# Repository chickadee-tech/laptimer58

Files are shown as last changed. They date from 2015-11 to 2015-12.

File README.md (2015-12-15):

# chickadee-laptimer-pcb
PCB design files for Chickadee Lap Timer.

See subfolders for licenses. Code is typically MIT Licensed and PCB designs are typically Creative Commons BY-SA.

Kicad files use components available in https://github.com/chickadee-tech/kicad-libs. It is assumed that this directory is ../shared/kicad/libraries/public/ relative to the root of this repository. You may find absolute paths that still need to be fixed. Please provide a pull request to fix those.

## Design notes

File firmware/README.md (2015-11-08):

# chickadee-firmware
Firmware for chickadee devices.

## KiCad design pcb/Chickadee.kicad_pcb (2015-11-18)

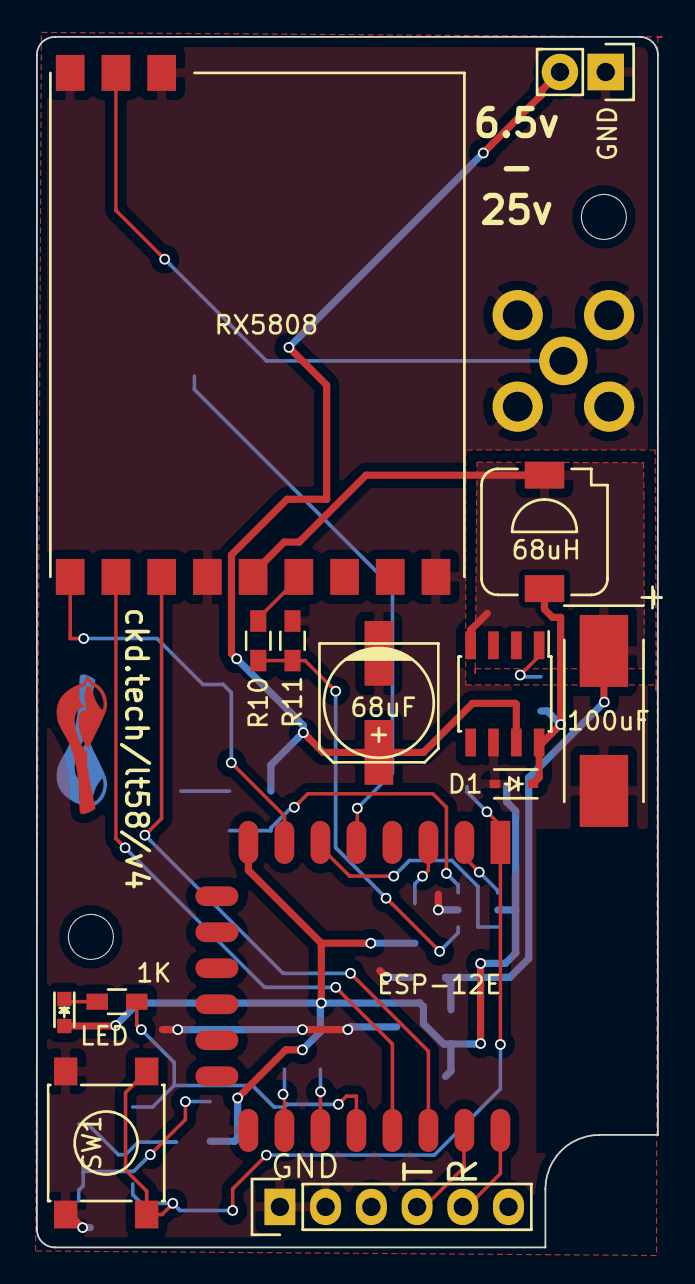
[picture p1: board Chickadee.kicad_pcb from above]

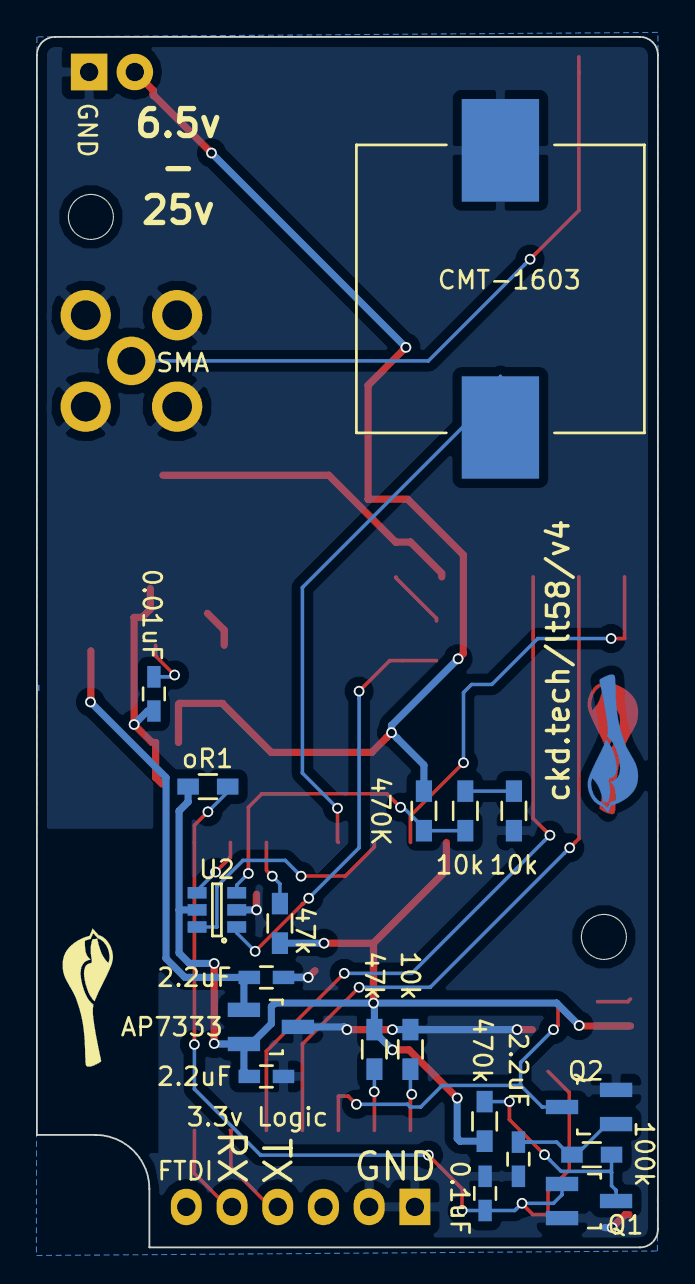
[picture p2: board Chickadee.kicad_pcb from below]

Board: 2 copper layers, 34.5 x 67.2 mm, 34 parts (19 on the bottom side), 27 nets.

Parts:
C1: 0.1uF; C_0603_HandSoldering
C2, C3, C4: 2.2uF; C_0603_HandSoldering
CB1: 0.01uF; C_0603_HandSoldering
Cin1: 68uF; c_elec_6.3x7.7
Cout1: 100uF; TantalC_SizeD_EIA-7343_HandSoldering
D1: SD103BWS-TP; SOD-323
D2: LED; LED-0603
J1: SMA; SMA-Jack-Straight
L1: 68uH; SLF7032
LS1: CMT-1603; CMT-1603-SMT
P1: FTDI; Pin_Header_Straight_1x06
P2: CONN_01X02; Pin_Header_Straight_1x02
Q1, Q2: Q_NMOS_GSD; SOT-23_Handsoldering
R1: 470k; R_0603_HandSoldering
R2: 100k; R_0603_HandSoldering
R3, R5: 47k; R_0603_HandSoldering
R4: 1K; R_0603_HandSoldering
R6, R8, R9, R11: 10k; R_0603_HandSoldering
R7: 470K; R_0603_HandSoldering
R10: 1k; R_0603_HandSoldering
RF1: RX5808; rx5808
SW1: SW_PUSH; SW_SPST_PTS645
U1: ESP-12E
U2: 74LVC1G3157; SOT-23-6
U3: LM2674M-3.3; SOIC-8_3.9x4.9mm_Pitch1.27mm
U4: AP7333; SOT-23_Handsoldering
oR1: 10k; R_0603_HandSoldering

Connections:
+3V3: C4.1, D2.2, R1.1, R3.2, R5.1, U1.8, U2.5, U4.2, oR1.1
+5V: C3.1, Cout1.1, L1.1, RF1.8, U3.4, U4.1
+BATT: Cin1.1, P2.2, R7.1, U3.7
/5V/3V3 Regulator/5uf: CB1.2, D1.1, L1.2, U3.8
/ADC_SELECT: U1.6, U2.6
/CLK: RF1.6, U1.20
/DATA: RF1.4, U1.7
/ESP-Reset/GPIO0: Q2.3, R4.2, U1.18
/ESP-Reset/RESET: C1.1, Q1.1, SW1.2, U1.1, oR1.2
/LE: RF1.5, U1.19
/RFIN: J1.1, RF1.2
/RSSI: R10.1, RF1.9
/RXI: P1.5, U1.22
/SHARED_ADC: U1.2, U2.4
/TXO: P1.4, U1.21
GNDPWR: C1.2, C2.2, C3.2, C4.2, Cin1.2, Cout1.2, D1.2, J1.2, J1.3, J1.4, J1.5, LS1.2, P1.1, P1.2, P2.1, Q1.2, Q2.2, R6.1, R9.2, R11.2, RF1.1, RF1.3, RF1.7, RF1.12, SW1.1, U1.15, U2.2, U3.6, U4.3
unnamed: C2.1, Q2.1, R2.1
unnamed: CB1.1, U3.1
unnamed: D2.1, R4.1
unnamed: LS1.1, U1.5
unnamed: Q1.3, R1.2, R2.2
unnamed: R3.1, U1.3
unnamed: R5.2, U1.17
unnamed: R6.2, U1.16
unnamed: R7.2, R8.1, U2.3
unnamed: R8.2, R9.1
unnamed: R10.2, R11.1, U2.1

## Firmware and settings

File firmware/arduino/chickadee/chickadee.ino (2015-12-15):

#include <ESP8266WiFi.h>
#include <WiFiUDP.h>
#include <EEPROM.h>

// Wifi related globals.
const char* SSID = "chickadee";
const char* PASSWORD = "iflyfast";

const IPAddress MULTICAST_ADDRESS(239, 249, 134, 147);
const uint16_t PORT = 59734;

// Radio related globals.
const unsigned int TUNE_TIME_MS = 30; // 30

// Cross-power up globals.
const uint32_t EEPROM_VERSION = 1;

const uint16_t MAX_JOIN_DELAY = 15000;

#define RSSI_READS 3 // used to be 10 but took 4ms

const int BOARD_LED = 0;
const int ESP_LED = 2;
const int SPEAKER = 14;
const int ADC_SELECT = 12;

const int RCV_CHIP_SELECT = 4;
const int RCV_CLK = 5;
const int RCV_DATA = 13;

const uint8_t PACKET_TYPE_NEW_CLIENT = 1;
const uint8_t PACKET_TYPE_NEW_PEER = 2;
const uint8_t PACKET_TYPE_I_AM_AP = 3;

const uint8_t PEER_LED_ON_CYCLE_COUNT = 2;
const uint8_t PEER_LED_BREAK_CYCLE_COUNT = 20;

const uint8_t ERROR_NO_WIFI = 1;
const uint8_t ERROR_MAX_CLIENTS = 2;
const uint8_t ERROR_MAX_PEERS = 3;

int errorCode = -1;

unsigned long lastReadTime;
unsigned long lastTuneTime;

IPAddress ourIp;

WiFiUDP udp;

// If we are the AP we must also forward packets from peers to clients.
bool isAP = false;

#define TCP_SERVER_PORT 59736
WiFiServer server(TCP_SERVER_PORT);

uint8_t controlPacket[] = {0, 0, 0, 0};

void setup() {
  Serial.begin(115200);
  delay(10);

  uint32_t chipId = ESP.getChipId();
  Serial.println(chipId);

  // Get our file counter.
  EEPROM.begin(12);
  uint32_t storedChipId;
  EEPROM.get(0, storedChipId);
  //Serial.println(storedChipId);
  // Initialize the eeprom completely.
  if (storedChipId != chipId) {
    EEPROM.put(0, chipId);
    EEPROM.put(4, EEPROM_VERSION);
  }
  EEPROM.end();

  pinMode(0, OUTPUT);
  
  // ADC_SELECT switches between measuring RSSI and battery voltage. v3 boards
  // don't have the battery voltage divider hooked up so we just set it to the
  // RSSI for good. LOW is the battery voltage.
  pinMode(ADC_SELECT, OUTPUT);
  digitalWrite(ADC_SELECT, HIGH);

  pinMode(BOARD_LED, OUTPUT);

  pinMode(ESP_LED, OUTPUT);
  digitalWrite(ESP_LED, HIGH);

  pinMode(RCV_DATA, OUTPUT);
  pinMode(RCV_CLK, OUTPUT);
  pinMode(RCV_CHIP_SELECT, OUTPUT);

  // Scan for an existing network.
  WiFi.mode(WIFI_STA);
  WiFi.disconnect();
  delay(100);

  int network_count = WiFi.scanNetworks();

  bool found_network = false;
  for (int i = 0; i < network_count; i++) {
    found_network = String(WiFi.SSID(i)).equals(String(SSID));
    if (found_network) {
      break;
    }
  }

  if (!found_network) {
    WiFi.mode(WIFI_AP_STA);
    WiFi.softAP(SSID, PASSWORD);
    ourIp = WiFi.softAPIP();

    Serial.println("Created network");
    isAP = true;
  } else {
    WiFi.begin(SSID, PASSWORD);
    uint16 total_delay = 0;
    while (WiFi.status() != WL_CONNECTED && total_delay < MAX_JOIN_DELAY) {
      delay(100);
      total_delay += 100;
    }
    if (WiFi.status() != WL_CONNECTED) {
      //Serial.println("WiFi join failed.");
      WiFi.printDiag(Serial);
      errorCode = ERROR_NO_WIFI;
      return;
    }
    
    Serial.println("Joined existing network.");
    ourIp = WiFi.localIP();
  }
  server.begin();
  //Serial.println(ourIp);
  udp.beginMulticast(ourIp, MULTICAST_ADDRESS, PORT);
  udp.beginPacketMulticast(MULTICAST_ADDRESS, PORT, ourIp);
  controlPacket[0] = PACKET_TYPE_NEW_PEER;
  controlPacket[1] = 0;
  controlPacket[2] = TCP_SERVER_PORT & 0xff;
  controlPacket[3] = TCP_SERVER_PORT >> 8;
  udp.write(controlPacket, sizeof(controlPacket));
  udp.endPacket();
}

// One iteration byte to detect missed packets.
// Four bytes for the time.
// Two bytes for the frequency.
// Two bytes for the strength.
uint8_t packet_size = 9;

uint8_t packetNo = 0;
uint16_t frequencies[] = {5800, 5740, 0, 0, 0, 0, 0};
uint16_t f_register[] = {0x2984, 0x2906, 0, 0, 0, 0, 0};
uint16_t lastValue = 0;
bool increasing = true;
uint16_t tuningFrequency = 0;
uint16_t tunedFrequency = 0;

// Clients are devices that want to get the data streamed back to them.
const int MAX_CLIENTS = 4;
WiFiClient clients[MAX_CLIENTS];
uint8_t numClients = 0;

// Only the AP node has peers. They are other devices that wish to send their data to the clients of the AP.
const int MAX_PEERS = 4;
WiFiClient peer[MAX_PEERS];
uint8_t numPeers = 0;

#define WIFI_MTU 1400 // buffer writes to the tcp connection to minimize tcp overhead

uint8_t tcp_client_buffer[WIFI_MTU * MAX_CLIENTS];
uint16_t tcp_client_buffer_size[MAX_CLIENTS];

uint8_t tcp_forward_buffer[WIFI_MTU];

uint8_t peerLedCycle = 0;

void loop() {
  // Handle errors by flashing/beeping an error code.
  if (errorCode > 0) {
    digitalWrite(BOARD_LED, LOW);
    delay(100);
    digitalWrite(BOARD_LED, HIGH);
    delay(75);
    digitalWrite(BOARD_LED, LOW);
    delay(100);
    digitalWrite(BOARD_LED, HIGH);
    delay(150);
    for (int i = 0; i < errorCode; i++) {
      digitalWrite(BOARD_LED, LOW);
      delay(350);
      digitalWrite(BOARD_LED, HIGH);
      delay(150);
    }
    delay(1000);
    return;
  }

  if (server.status() == LISTEN) {
    // Accept any new clients.
    WiFiClient newClient = server.available();
    while (newClient && numClients < MAX_CLIENTS) {
      Serial.println("Accepted new client tcp socket.");
      clients[numClients] = newClient;
      
      // We prefix our packets with the chip id so it can be differentiated from our peers.
      uint32_t chip_id = ESP.getChipId();
      uint16_t base_offset = WIFI_MTU * numClients;
      tcp_client_buffer[base_offset] = (char) (chip_id >> 24);
      tcp_client_buffer[base_offset + 1] = (char) (chip_id >> 16);
      tcp_client_buffer[base_offset + 2] = (char) (chip_id >> 8);
      tcp_client_buffer[base_offset + 3] = (char) chip_id;
      tcp_client_buffer_size[numClients] = 4;
      
      numClients++;
      newClient = server.available();
    }
    if (!isAP) {
      if (numClients > 0) {
        digitalWrite(ESP_LED, LOW);
      } else {
        digitalWrite(ESP_LED, HIGH);
      }
    }
  } else {
    // Forward any tcp packets we've received to all of our clients.
    for (int i = 0; i < numPeers; i++) {
      if (peer[i].available()) {
        uint16_t read_size = peer[i].read(tcp_forward_buffer, WIFI_MTU);
        Serial.println(read_size);
        for (int j = 0; j < numClients; j++) {
          clients[j].write((const uint8_t *) tcp_forward_buffer, read_size);
        }
      }
    }
  }

  // Read any UDP hello packets we've received.
  while (udp.parsePacket() > 0) {
    Serial.print("Got udp packet of length ");
    Serial.println(udp.available());

    int packet_type = udp.read();
    // Clients such as phones announce themselves and receive a UDP packet back from the AP.
    // They then need to initiate the TCP connection. (This decision was made because react-native
    // has no TCP server bindings only TCP client.)
    if (packet_type == PACKET_TYPE_NEW_CLIENT) {
      // We only reply to the address that announced itself. Receiving a multicast isn't working on iOS.
      udp.beginPacket(udp.remoteIP(), PORT);
      controlPacket[0] = PACKET_TYPE_I_AM_AP;
      controlPacket[1] = 0;
      controlPacket[2] = TCP_SERVER_PORT & 0xff;
      controlPacket[3] = TCP_SERVER_PORT >> 8;
      udp.write(controlPacket, sizeof(controlPacket));
      udp.endPacket();
      Serial.println("sent I_AM_AP back");
      Serial.println(sizeof(controlPacket));
    } else if (packet_type == PACKET_TYPE_NEW_PEER) {
      // New peer is announced once when a device is turned on. If we are the AP then we connect to the peer's TCP server.
      udp.read();
      uint16_t tcp_port = ((uint16_t) udp.read());
      tcp_port = tcp_port | ((uint16_t) udp.read()) << 8;
 
      IPAddress new_peer_ip = udp.remoteIP();
      if (isAP) {
        int peer_index = -1;
        for (int j = 0; j < numPeers; j++) {
          if (peer[j].remoteIP() == new_peer_ip) {
            peer_index = j;
            break;
          }
        }

        if (numPeers == MAX_PEERS && peer_index == -1) {
          errorCode = ERROR_MAX_PEERS;
          return;
        }

        if (peer_index == -1) {
          peer_index = numPeers;
        }

        if (peer[peer_index].connect(new_peer_ip, tcp_port)) {
          numPeers++;
        }
      }
    } else {
      Serial.print("Unknown packet type");
      Serial.println(packet_type);
    }
    udp.flush();
  }

  // TODO(tannewt): Garbage collect stale WiFi clients so we can reuse them.

  // Turn on the LED to show we're working but only for the first frequency read.
  digitalWrite(BOARD_LED, LOW);
  int i = 0;
  while (frequencies[i] != 0) {
    if (tunedFrequency != 0) {
      packetNo++;
      for (int j = 0; j < numClients; j++) {
        uint16_t base_offset = WIFI_MTU * j + tcp_client_buffer_size[j];
        tcp_client_buffer[base_offset] = packetNo;
        tcp_client_buffer[base_offset + 1] = (char) (lastReadTime >> 24);
        tcp_client_buffer[base_offset + 2] = (char) (lastReadTime >> 16);
        tcp_client_buffer[base_offset + 3] = (char) (lastReadTime >> 8);
        tcp_client_buffer[base_offset + 4] = (char) lastReadTime;
        tcp_client_buffer[base_offset + 5] = (char) (tunedFrequency >> 8);
        tcp_client_buffer[base_offset + 6] = (char) tunedFrequency;
        tcp_client_buffer[base_offset + 7] = (char) (lastValue >> 8);
        tcp_client_buffer[base_offset + 8] = lastValue;
        tcp_client_buffer_size[j] += packet_size;
        if (WIFI_MTU - tcp_client_buffer_size[j] < packet_size) {
          // TODO(tannewt): Use something else. This blocks on receiving a TCP ack!
          clients[j].write(((const uint8_t *)tcp_client_buffer) + WIFI_MTU * j, tcp_client_buffer_size[j]);
          Serial.print("Wrote buffer to client ");
          Serial.println(j);
          // Reset back to 4 buffer size because the first four bytes are chip id.
          tcp_client_buffer_size[j] = 4;
        }
      }
      
//      Serial.print(lastReadTime);
//      Serial.print(" ");
//      Serial.print(tunedFrequency);
//      Serial.print(" ");
//      Serial.println(lastValue);
    }
    if (tuningFrequency != 0) {
      if (tuningFrequency != tunedFrequency) {
        // Wait the remainder of the tune time if we actually had to tune.
        int delay_time = TUNE_TIME_MS - (millis() - lastTuneTime);
        //Serial.println(delay_time);
        if (delay_time > 0) {
          delay(delay_time);
        }
      }
      tunedFrequency = tuningFrequency;

      // Read value.
      lastValue = 0;
      for (uint8_t i = 0; i < RSSI_READS; i++) {
        lastValue += analogRead(A0);
      }
      lastValue = lastValue / RSSI_READS;
      //Serial.println(lastValue);
      //Serial.print(tunedFrequency);
      //Serial.print(" ");
      //Serial.println(lastValue);
      lastReadTime = millis();
    }
    // Tune radio.
    tuningFrequency = frequencies[i];
    if (tuningFrequency != tunedFrequency) {
      RCV_FREQ(f_register[i]);
    }
    
    lastTuneTime = millis();
    i++;
    digitalWrite(BOARD_LED, HIGH);

    // If we are the AP, then blink the ESP LED to indicate the number of connected peers.
    if (isAP) {
      if (numPeers > 0 && peerLedCycle <= PEER_LED_ON_CYCLE_COUNT * 2 * numPeers && peerLedCycle % PEER_LED_ON_CYCLE_COUNT == 0) {
        uint8_t i = peerLedCycle / PEER_LED_ON_CYCLE_COUNT;
        if (i % 2 == 0) {
          digitalWrite(ESP_LED, HIGH);
        } else {
          digitalWrite(ESP_LED, LOW);
        }
      }
      if (peerLedCycle == PEER_LED_ON_CYCLE_COUNT * 2 * numPeers + PEER_LED_BREAK_CYCLE_COUNT) {
        peerLedCycle = 0;
      }  else {
        peerLedCycle++;
      }
    }
  }
}

/*
 * SPI driver based on fs_skyrf_58g-main.c Written by Simon Chambers
 * TVOUT by Myles Metzel
 * Scanner by Johan Hermen
 * Inital 2 Button version by Peter (pete1990)
 * Refactored and GUI reworked by Marko Hoepken
 * Universal version my Marko Hoepken
 * Diversity Receiver Mode and GUI improvements by Shea Ivey
 * OLED Version by Shea Ivey
 * Seperating display concerns by Shea Ivey
 * 
The MIT License (MIT)
Copyright (c) 2015 Marko Hoepken
Permission is hereby granted, free of charge, to any person obtaining a copy
of this software and associated documentation files (the "Software"), to deal
in the Software without restriction, including without limitation the rights
to use, copy, modify, merge, publish, distribute, sublicense, and/or sell
copies of the Software, and to permit persons to whom the Software is
furnished to do so, subject to the following conditions:
The above copyright notice and this permission notice shall be included in all
copies or substantial portions of the Software.

THE SOFTWARE IS PROVIDED "AS IS", WITHOUT WARRANTY OF ANY KIND, EXPRESS OR
IMPLIED, INCLUDING BUT NOT LIMITED TO THE WARRANTIES OF MERCHANTABILITY,
FITNESS FOR A PARTICULAR PURPOSE AND NONINFRINGEMENT. IN NO EVENT SHALL THE
AUTHORS OR COPYRIGHT HOLDERS BE LIABLE FOR ANY CLAIM, DAMAGES OR OTHER
LIABILITY, WHETHER IN AN ACTION OF CONTRACT, TORT OR OTHERWISE, ARISING FROM,
OUT OF OR IN CONNECTION WITH THE SOFTWARE OR THE USE OR OTHER DEALINGS IN THE
SOFTWARE.
*/
void RCV_FREQ(uint16_t channelData) {
  uint8_t j;
  // Second is the channel data from the lookup table
  // 20 bytes of register data are sent, but the MSB 4 bits are zeros
  // register address = 0x1, write, data0-15=channelData data15-19=0x0
  SERIAL_ENABLE_HIGH();
  SERIAL_ENABLE_LOW();

  // Register 0x1
  SERIAL_SENDBIT1();
  SERIAL_SENDBIT0();
  SERIAL_SENDBIT0();
  SERIAL_SENDBIT0();

  // Write to register
  SERIAL_SENDBIT1();

  // D0-D15
  //   note: loop runs backwards as more efficent on AVR
  for (j = 16; j > 0; j--)
  {
    // Is bit high or low?
    if (channelData & 0x1)
    {
      SERIAL_SENDBIT1();
    }
    else
    {
      SERIAL_SENDBIT0();
    }

    // Shift bits along to check the next one
    channelData >>= 1;
  }

  // Remaining D16-D19
  for (j = 4; j > 0; j--)
    SERIAL_SENDBIT0();

  // Finished clocking data in
  SERIAL_ENABLE_HIGH();
  delayMicroseconds(1);
  //delay(2);

  digitalWrite(RCV_CHIP_SELECT, LOW);
  digitalWrite(RCV_CLK, LOW);
  digitalWrite(RCV_DATA, LOW);
}

void SERIAL_SENDBIT1()
{
  digitalWrite(RCV_CLK, LOW);
  delayMicroseconds(1);

  digitalWrite(RCV_DATA, HIGH);
  delayMicroseconds(1);
  digitalWrite(RCV_CLK, HIGH);
  delayMicroseconds(1);

  digitalWrite(RCV_CLK, LOW);
  delayMicroseconds(1);
}

void SERIAL_SENDBIT0()
{
  digitalWrite(RCV_CLK, LOW);
  delayMicroseconds(1);

  digitalWrite(RCV_DATA, LOW);
  delayMicroseconds(1);
  digitalWrite(RCV_CLK, HIGH);
  delayMicroseconds(1);

  digitalWrite(RCV_CLK, LOW);
  delayMicroseconds(1);
}

void SERIAL_ENABLE_LOW()
{
  delayMicroseconds(1);
  digitalWrite(RCV_CHIP_SELECT, LOW);
  delayMicroseconds(1);
}

void SERIAL_ENABLE_HIGH()
{
  delayMicroseconds(1);
  digitalWrite(RCV_CHIP_SELECT, HIGH);
  delayMicroseconds(1);
}

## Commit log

2015-11-08 Add 'laptimer/' from commit 'ad23e0cf0ae844a5073d6c5f4a7300dd6b9fdc45'
    git-subtree-dir: laptimer
    git-subtree-mainline: d5137dc4f598fd388e51b94a87d69fd50ee67068
    git-subtree-split: ad23e0cf0ae844a5073d6c5f4a7300dd6b9fdc45
    [Chickadee-B.Cu.gbl, Chickadee-B.Mask.gbs, Chickadee-B.SilkS.gbo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]
2015-11-08 Laptimer PCB firmware.
2015-11-08 Add 'laptimer/tools/log_analysis/' from commit 'c05ad9e7786d40f8d711c20d9a6ed2dc90feb600'
    git-subtree-dir: laptimer/tools/log_analysis
    git-subtree-mainline: 7574998d6e02a5272a75e4a79d0b8d64e1a74f9c
    git-subtree-split: c05ad9e7786d40f8d711c20d9a6ed2dc90feb600
    [0001_golden.csv]
2015-11-08 Move pcb files to their own directory.
    [Chickadee.kicad_pcb, Chickadee.sch, ESP-Reset.sch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]
2015-11-17 Update the Laptimer firmware code for PCB v3
2015-11-17 Move gerber folder
    [Chickadee-B.Cu.gbl, Chickadee-B.Mask.gbs, Chickadee-B.SilkS.gbo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]
2015-11-18 v4 of laptimer with everything connected and RSSI voltage divider.
    [Chickadee-B.Cu.gbl, Chickadee-B.Mask.gbs, Chickadee-B.SilkS.gbo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]
2015-11-27 Get TCP connections back from the Chickadee.
    [Chickadee.kicad_pcb]
2015-12-04 Touched the pcb files with a new version of Kicad.
    [Chickadee.kicad_pcb]
2015-12-07 tweaks to pcb
    [Chickadee.kicad_pcb]
2015-12-07 Print the first value received in each group to get a glimpse of the data being recorded.
2015-12-07 Add licenses and a little more explanation.
    [Chickadee.sch, ESP-Reset.sch, Regulator.sch]
2015-12-17 Introduce a replay.js script to run sample analysis on a previously recorded file. It will also render a plot of the data for debugging.
2015-12-18 Add logging of all devices to a single file and get it working on a real phone.
